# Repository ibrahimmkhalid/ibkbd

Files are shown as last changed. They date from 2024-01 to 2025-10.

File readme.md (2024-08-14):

# IBKBD
_Ibrahim's Keyboards_

- IBKBD Full
    - Custom physical layout, PCB, Case, and keymap
    - 4x6 + 5 + 3 _(Inspired heavily by [Dygma Defy](https://dygma.com/products/dygma-defy))_
    - Generic DSA keycaps
    - Kailh Midnight Pro Silent Tactile Switches
    - Pro Micro ATmega32U4 with type C port
    - check ./ibkbd-full/ for all relevant files

- IBKBD Mini
    - Custom physical layout, PCB, Case, and keymap
    - 3x5 + 3 (Inspired by Absolem and Corne keyboards)
    - DDC Choc keycaps
    - Sunset Tactile Choc Switches
    - NiceNano v2
    - check ./ibkbd-mini/ for all relevant files

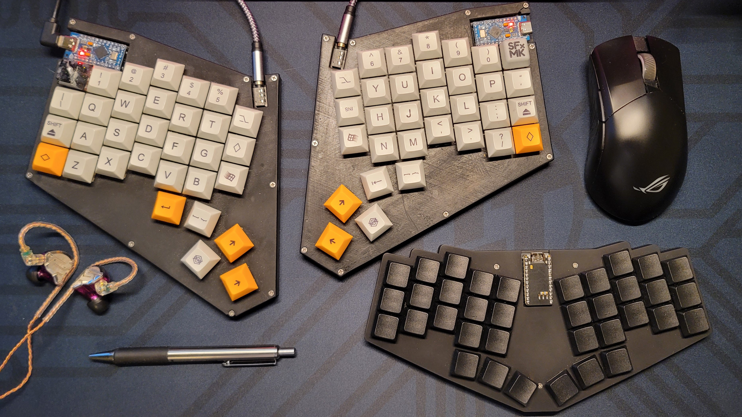
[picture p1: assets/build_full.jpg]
Final product

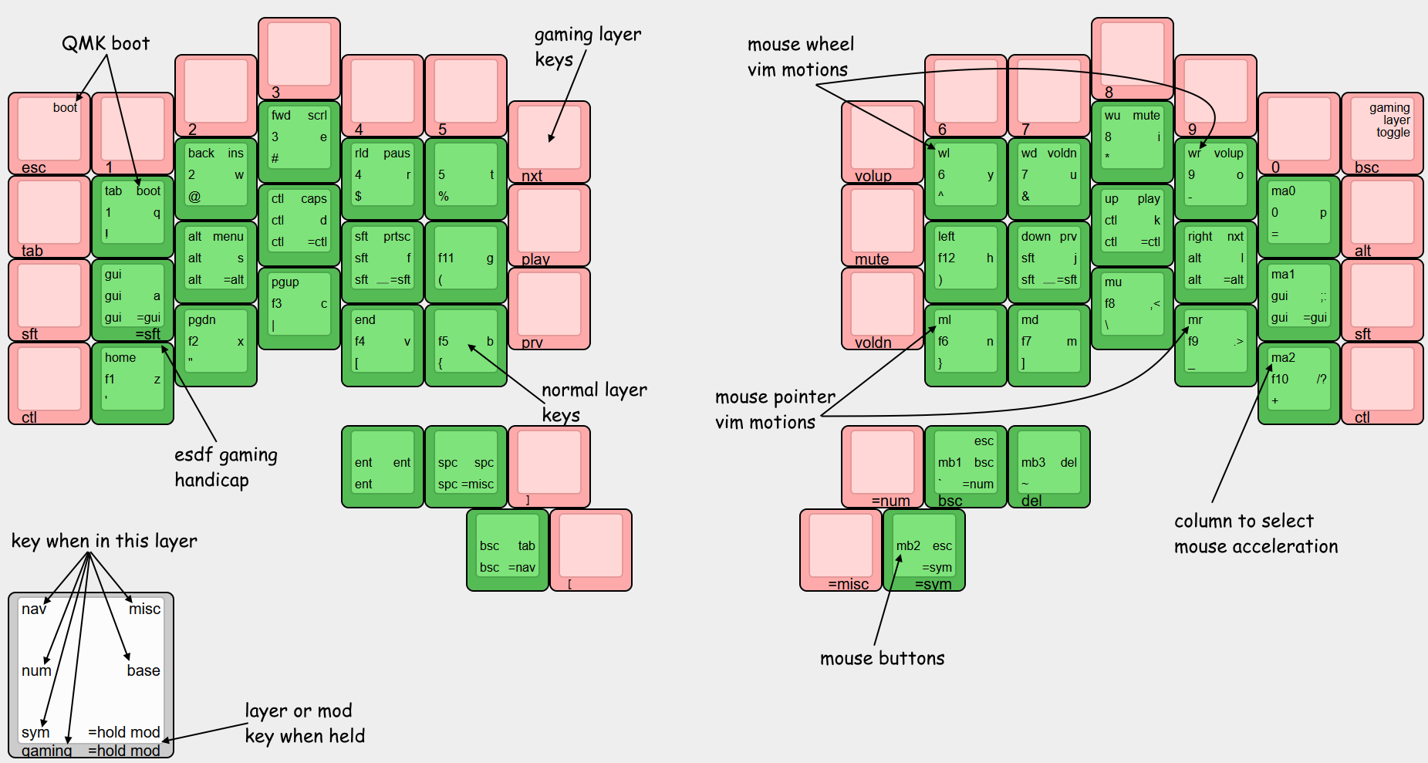
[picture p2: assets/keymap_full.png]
Keymap image


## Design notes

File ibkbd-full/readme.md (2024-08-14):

# IBKBD

_Ibrahim's Keyboard_

- Custom physical layout, PCB, Case, and keymap
- 4x6 + 5 + 3 _(Inspired heavily by [Dygma Defy](https://dygma.com/products/dygma-defy))_
- Generic DSA keycaps
- Kailh Midnight Pro Silent Tactile Switches
- Pro Micro ATmega32U4 with type C port

Originally, I was using all the keys in my base layer when i started my journey in ergonomic keyboards. Over time I was able to learn to use less keys and rely on better layer management. Though gaming is still best achieved when using the full board size. Current default layout is inspired by [Miryoku](https://github.com/manna-harbour/miryoku). My original keymap that used all keys on the board is saved in the "full" keymap.c file

#### In this project

- kicad pcb files
- 3D case files
- qmk configuration
- kle input

Keymap image

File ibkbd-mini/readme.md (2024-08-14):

# IBKBD

_Ibrahim's Keyboard_

- Custom physical layout, PCB, Case, and keymap
- 3x5 + 3 (Inspired by Absolem and Corne keyboards)
- DDC Choc keycaps
- Sunset Tactile Choc Switches
- NiceNano v2

I wanted to create an ultra portable version of the IBKBD-Full. This version uses low profile choc switches, does not have the gaming layer keys, and is a uni-body design.

#### In this project

- ergogen config
- completed kicad pcb
- generated 3d printing case files
- qmk keymap (substitute NiceNano)
- zmk keymap

Keymap image

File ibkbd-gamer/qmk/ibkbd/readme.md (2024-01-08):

# ibkbd

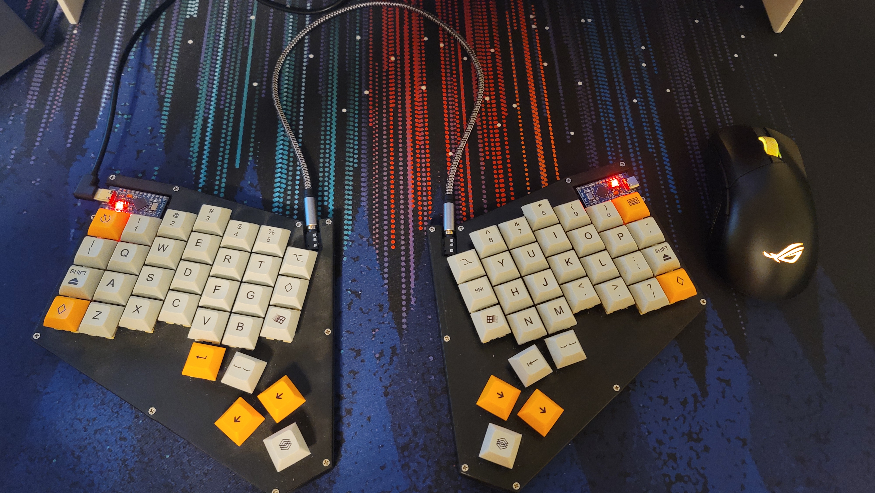
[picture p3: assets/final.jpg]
ibkbd


*A short description of the keyboard/project*

* Keyboard Maintainer: [Ibrahim Mansoor Khalid](https://github.com/ibrahimmkhalid)
* Hardware Supported: atmega32u4
* PCB and Case files: [ibrahimmkhalid/ibkbd](https://github.com/ibrahimmkhalid/ibkbd)

Make example for this keyboard (after setting up your build environment):

    make ibkbd:default

Flashing example for this keyboard:

    make ibkbd:default:flash

See the [build environment setup](https://docs.qmk.fm/#/getting_started_build_tools) and the [make instructions](https://docs.qmk.fm/#/getting_started_make_guide) for more information. Brand new to QMK? Start with our [Complete Newbs Guide](https://docs.qmk.fm/#/newbs).

## Bootloader

Enter the bootloader in 3 ways:

* **Bootmagic reset**: Hold down the key at (0,0) in the matrix (usually the top left key or Escape) and plug in the keyboard
* **Physical reset button**: Briefly press the button on the back of the PCB - some may have pads you must short instead
* **Keycode in layout**: Press the key mapped to `QK_BOOT` if it is available

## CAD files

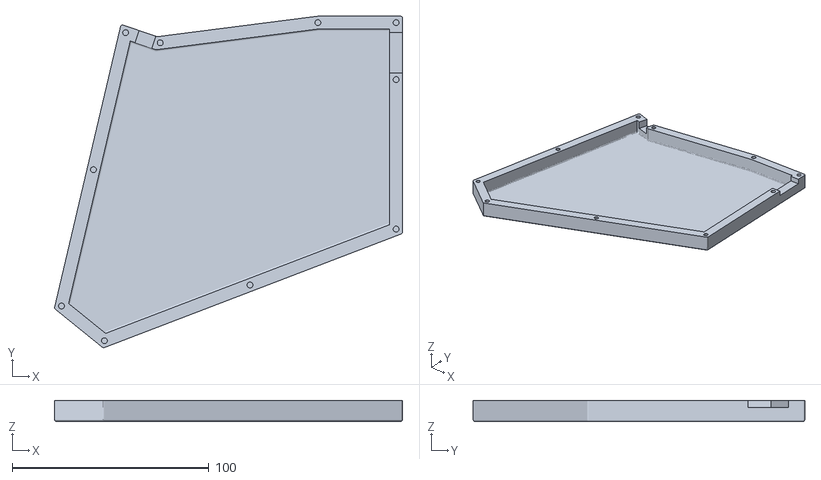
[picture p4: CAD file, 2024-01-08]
3d-files/base_right.stl
176.7 x 168.4 x 10.7

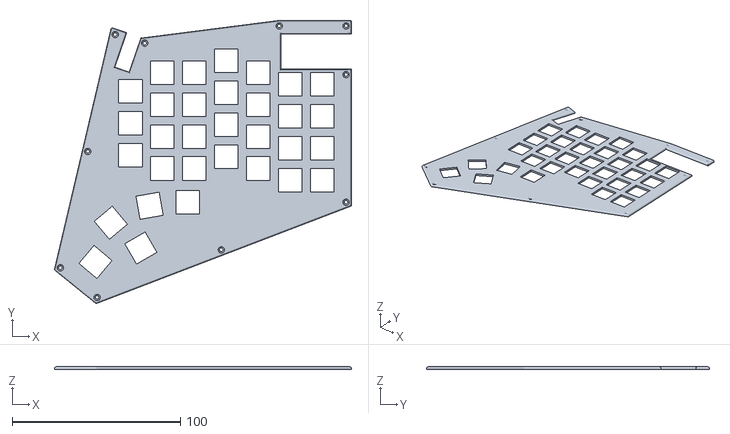
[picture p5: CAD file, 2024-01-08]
ibkbd-full/3d-files/plate_right.stl
176.7 x 168.4 x 1.50

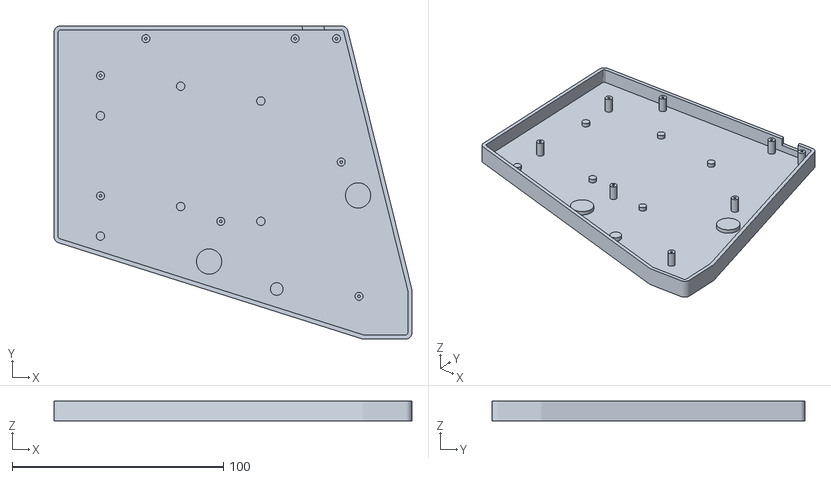
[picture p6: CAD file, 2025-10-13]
ibkbd-gamer/3d-files/bottom_plate.stl
169.6 x 148.3 x 9.40

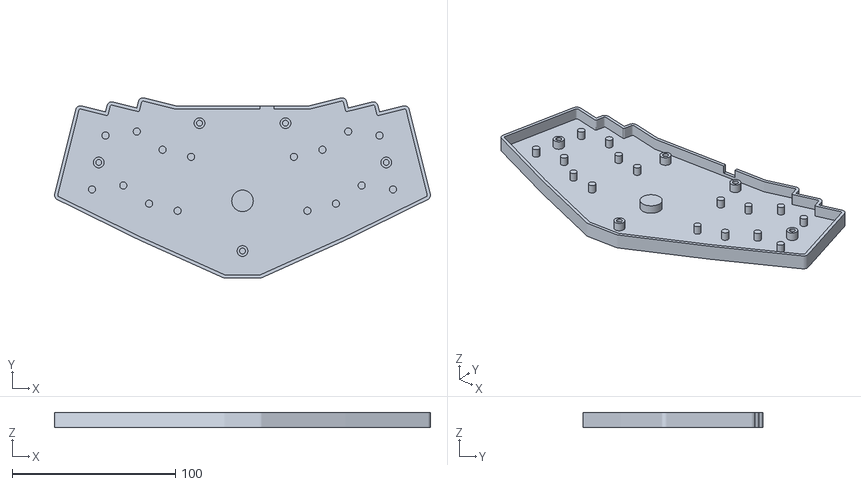
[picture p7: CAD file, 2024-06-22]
ibkbd-mini/3d-files/bottom_plate.stl
230.0 x 110.3 x 8.90

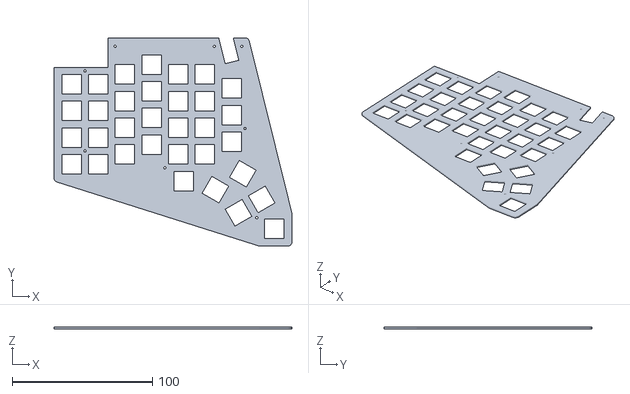
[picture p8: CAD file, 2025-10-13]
ibkbd-gamer/3d-files/top_plate.stl
169.6 x 148.3 x 1.20

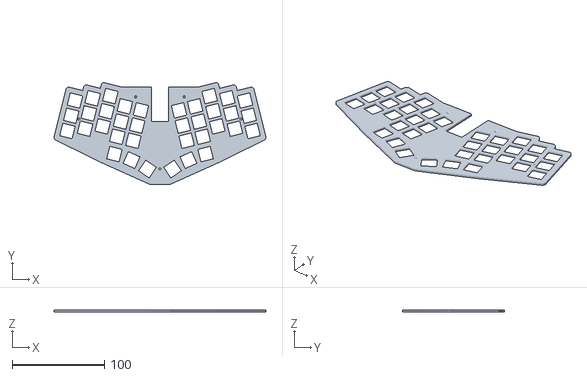
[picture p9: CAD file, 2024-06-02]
ibkbd-mini/3d-files/top_plate.stl
230.0 x 110.3 x 2.00

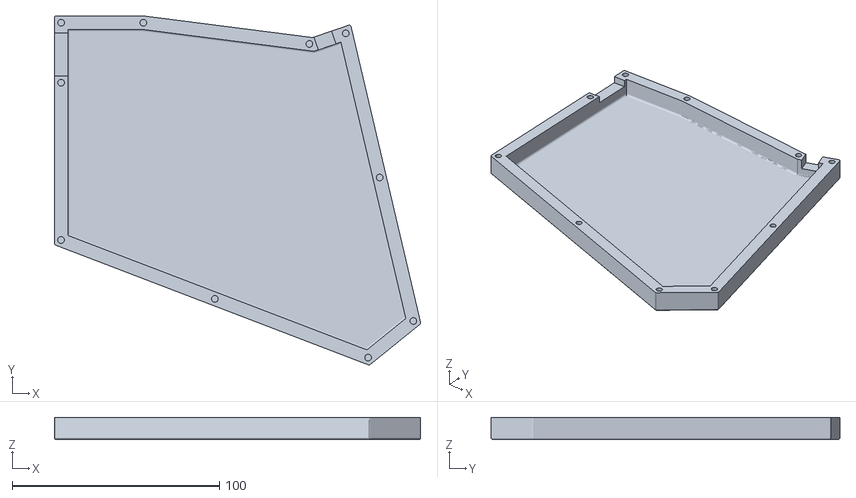
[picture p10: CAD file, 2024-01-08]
3d-files/base_left.stl
176.7 x 168.4 x 10.7

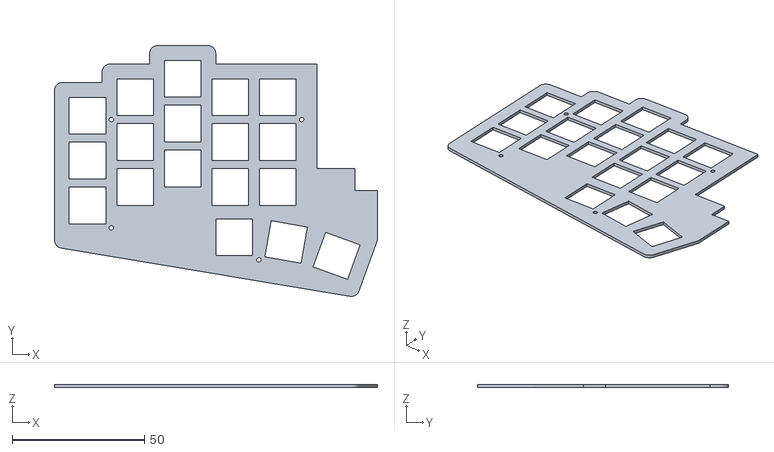
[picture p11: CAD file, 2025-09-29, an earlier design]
ibkbd-mini-split/3d-files/top_plate.stl
122.2 x 95.0 x 1.20

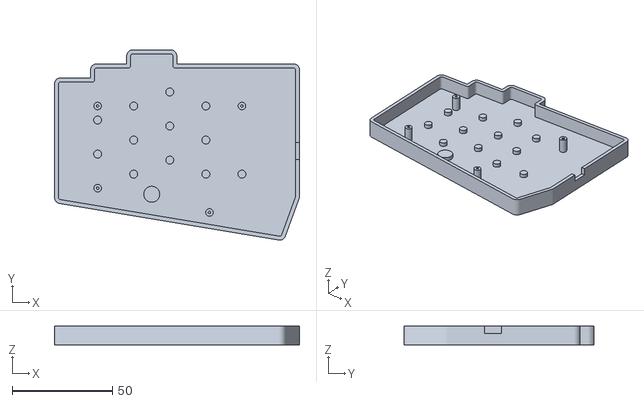
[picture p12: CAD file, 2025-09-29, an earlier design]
ibkbd-mini-split/3d-files/bottom_plate.stl
122.2 x 95.0 x 9.40

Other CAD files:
3d-files/plate_left.stl
ibkbd-full/3d-files/plate_left.stl

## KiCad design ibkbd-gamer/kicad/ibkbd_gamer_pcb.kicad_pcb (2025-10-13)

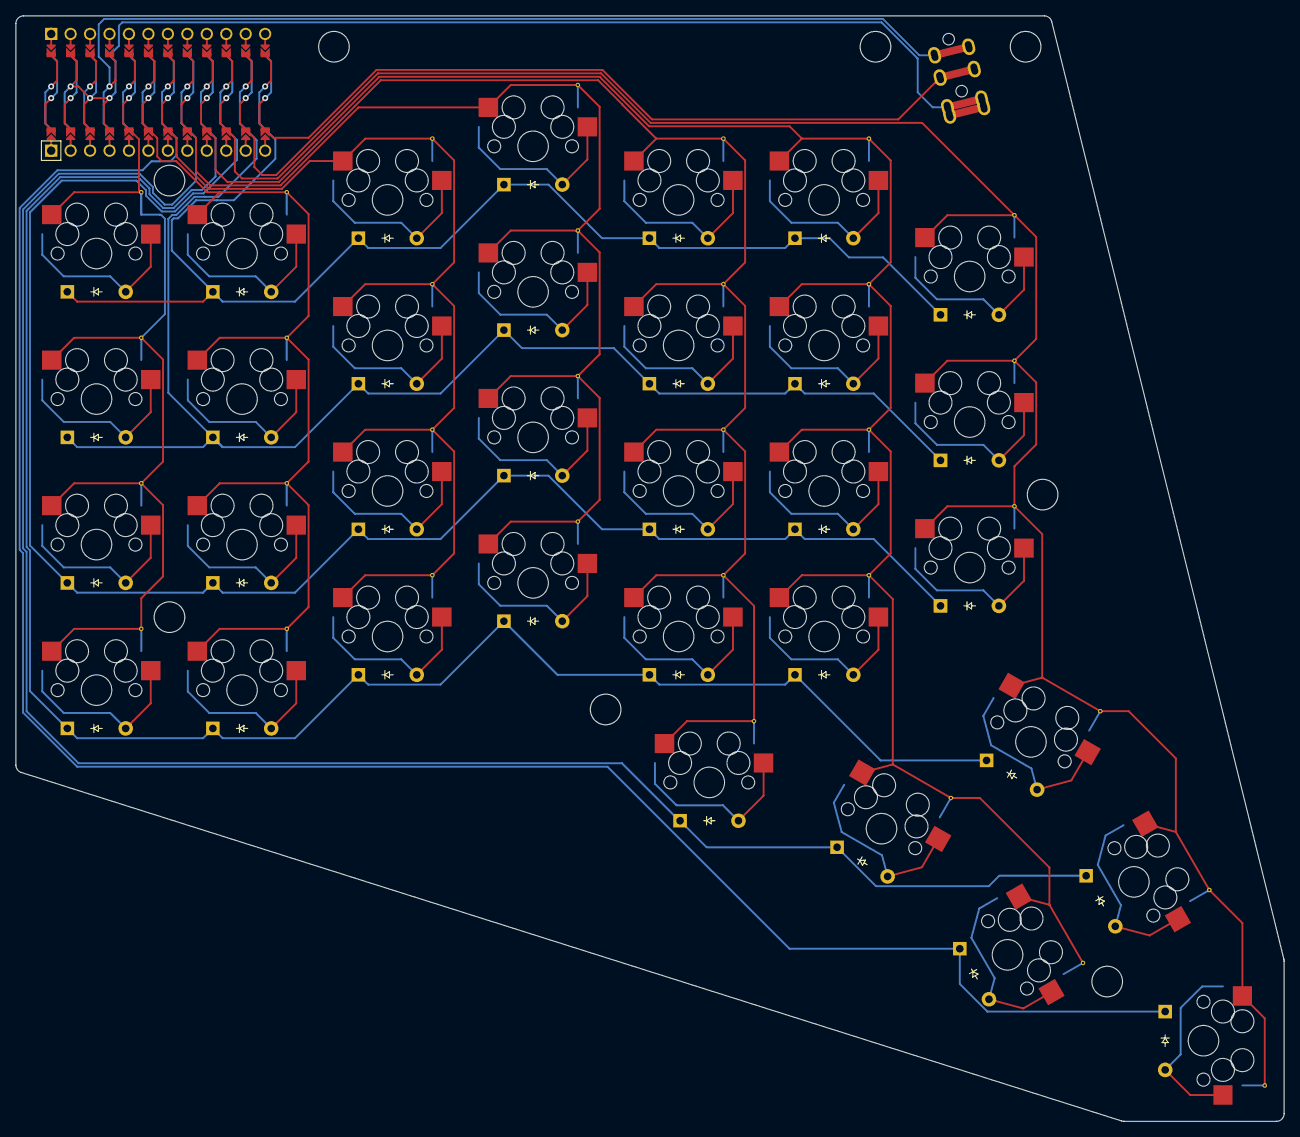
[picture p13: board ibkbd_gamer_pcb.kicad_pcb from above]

Board: 2 copper layers, 165.6 x 144.3 mm, 35 parts (0 on the bottom side), 16 nets.

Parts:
MCU1: ProMicro
S1, S2, S3, S4, S5, S6, S7, S8, S9, S10, S11, S12, S13, S14, S15, S16, S17, S18, S19, S20, S21, S22, S23, S24, S25, S26, S27, S28, S29, S30, S31, S32, S33: MXWD
TRRS1: TRRS-PJ-320A-dual

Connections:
GND: MCU1.2, MCU1.21, MCU1.22, TRRS1.1, TRRS1.2
P2: MCU1.20, S1.1, S2.1, S3.1, S4.1
P3: MCU1.19, S5.1, S6.1, S7.1, S8.1
P4: MCU1.18, S9.1, S10.1, S11.1, S12.1
P5: MCU1.17, S13.1, S14.1, S15.1, S16.1
P6: MCU1.16, S17.1, S18.1, S19.1, S20.1, S28.1
P7: MCU1.15, S21.1, S22.1, S23.1, S24.1, S29.1, S30.1
P8: MCU1.14, S25.1, S26.1, S27.1, S31.1, S32.1, S33.1
P9: MCU1.13, TRRS1.3
P10: MCU1.12, S4.2, S8.2, S12.2, S16.2, S20.2, S24.2, S27.2
P14: MCU1.10, S2.2, S6.2, S10.2, S14.2, S18.2, S22.2, S25.2
P15: MCU1.9, S1.2, S5.2, S9.2, S13.2, S17.2, S21.2, S32.2
P16: MCU1.11, S3.2, S7.2, S11.2, S15.2, S19.2, S23.2, S26.2
P18: MCU1.8, S28.2, S29.2, S31.2
P19: MCU1.7, S30.2, S33.2
VCC: MCU1.4, TRRS1.4

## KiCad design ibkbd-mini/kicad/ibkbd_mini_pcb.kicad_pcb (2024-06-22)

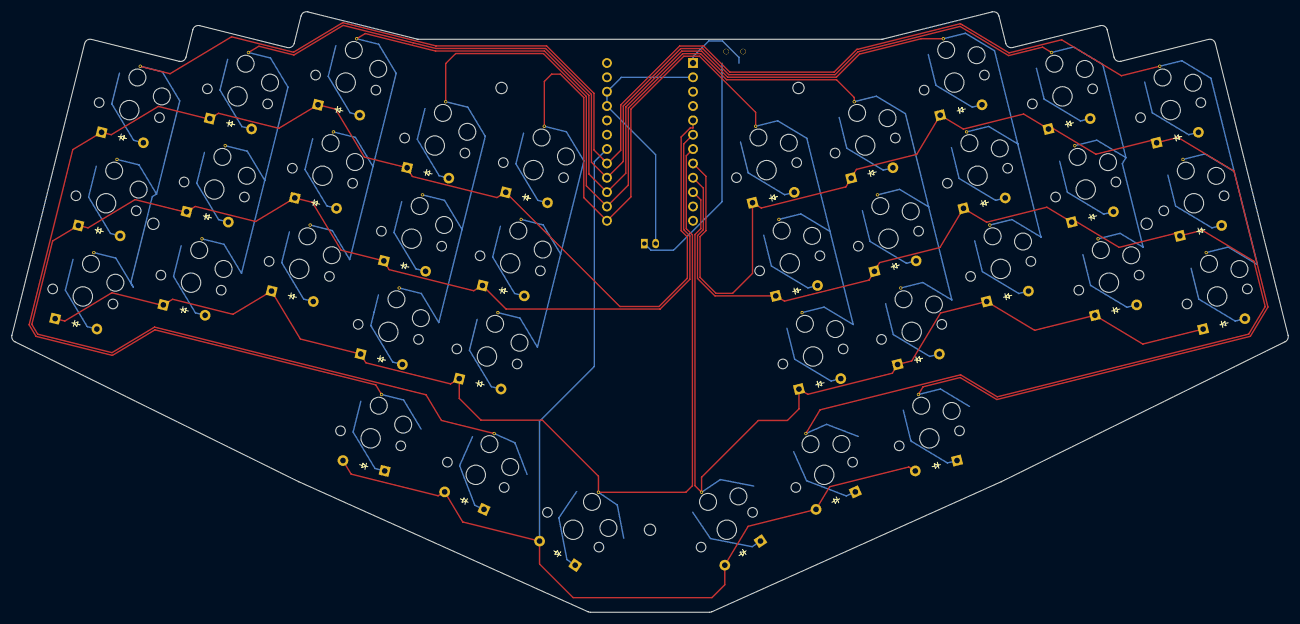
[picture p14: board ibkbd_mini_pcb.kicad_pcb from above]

Board: 2 copper layers, 226.0 x 106.3 mm, 75 parts (1 on the bottom side), 51 nets.

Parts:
D1, D2, D3, D4, D5, D6, D7, D8, D9, D10, D11, D12, D13, D14, D15, D16, D17, D18, D19, D20, D21, D22, D23, D24, D25, D26, D27, D28, D29, D30, D31, D32, D33, D34, D35, D36: ComboDiode
JST1: JST_PH_S2B-PH-K_02x2.00mm_Angled
MCU1: ProMicro
S1, S2, S3, S4, S5, S6, S7, S8, S9, S10, S11, S12, S13, S14, S15, S16, S17, S18, S19, S20, S21, S22, S23, S24, S25, S26, S27, S28, S29, S30, S31, S32, S33, S34, S35, S36: PG1350
T1: SPDT_C128955

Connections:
GND: JST1.2, MCU1.2, MCU1.15, MCU1.16
P4: D31.2, D32.2, D33.2, D34.2, D35.2, D36.2, MCU1.19
P5: MCU1.20, S1.2, S2.2, S3.2, S16.2, S17.2, S18.2
P6: MCU1.21, S4.2, S5.2, S6.2, S19.2, S20.2, S21.2
P7: MCU1.22, S7.2, S8.2, S9.2, S22.2, S23.2, S24.2
P8: MCU1.23, S10.2, S11.2, S12.2, S25.2, S26.2, S27.2
P9: MCU1.24, S13.2, S14.2, S15.2, S28.2, S29.2, S30.2
P14: D16.1, D19.1, D22.1, D25.1, D28.1, MCU1.10, S36.2
P15: D17.1, D20.1, D23.1, D26.1, D29.1, MCU1.9, S35.2
P18: D18.1, D21.1, D24.1, D27.1, D30.1, MCU1.8, S34.2
P19: D1.1, D4.1, D7.1, D10.1, D13.1, MCU1.7, S33.2
P20: D2.1, D5.1, D8.1, D11.1, D14.1, MCU1.6, S32.2
P21: D3.1, D6.1, D9.1, D12.1, D15.1, MCU1.5, S31.2
RAW: MCU1.1, T1.2
batswitch: JST1.1, T1.1
index_bottom: D10.2, S10.1
index_home: D11.2, S11.1
index_top: D12.2, S12.1
inner_bottom: D13.2, S13.1
inner_home: D14.2, S14.1
inner_key: D31.1, S31.1
inner_top: D15.2, S15.1
mid_key: D32.1, S32.1
middle_bottom: D7.2, S7.1
middle_home: D8.2, S8.1
middle_top: D9.2, S9.1
mirror_index_bottom: D25.2, S25.1
mirror_index_home: D26.2, S26.1
mirror_index_top: D27.2, S27.1
mirror_inner_bottom: D28.2, S28.1
mirror_inner_home: D29.2, S29.1
mirror_inner_key: D34.1, S34.1
mirror_inner_top: D30.2, S30.1
mirror_mid_key: D35.1, S35.1
mirror_middle_bottom: D22.2, S22.1
mirror_middle_home: D23.2, S23.1
mirror_middle_top: D24.2, S24.1
mirror_outer_key: D36.1, S36.1
mirror_pinky_bottom: D16.2, S16.1
mirror_pinky_home: D17.2, S17.1
mirror_pinky_top: D18.2, S18.1
mirror_ring_bottom: D19.2, S19.1
mirror_ring_home: D20.2, S20.1
mirror_ring_top: D21.2, S21.1
outer_key: D33.1, S33.1
pinky_bottom: D1.2, S1.1
pinky_home: D2.2, S2.1
pinky_top: D3.2, S3.1
ring_bottom: D4.2, S4.1
ring_home: D5.2, S5.1
ring_top: D6.2, S6.1

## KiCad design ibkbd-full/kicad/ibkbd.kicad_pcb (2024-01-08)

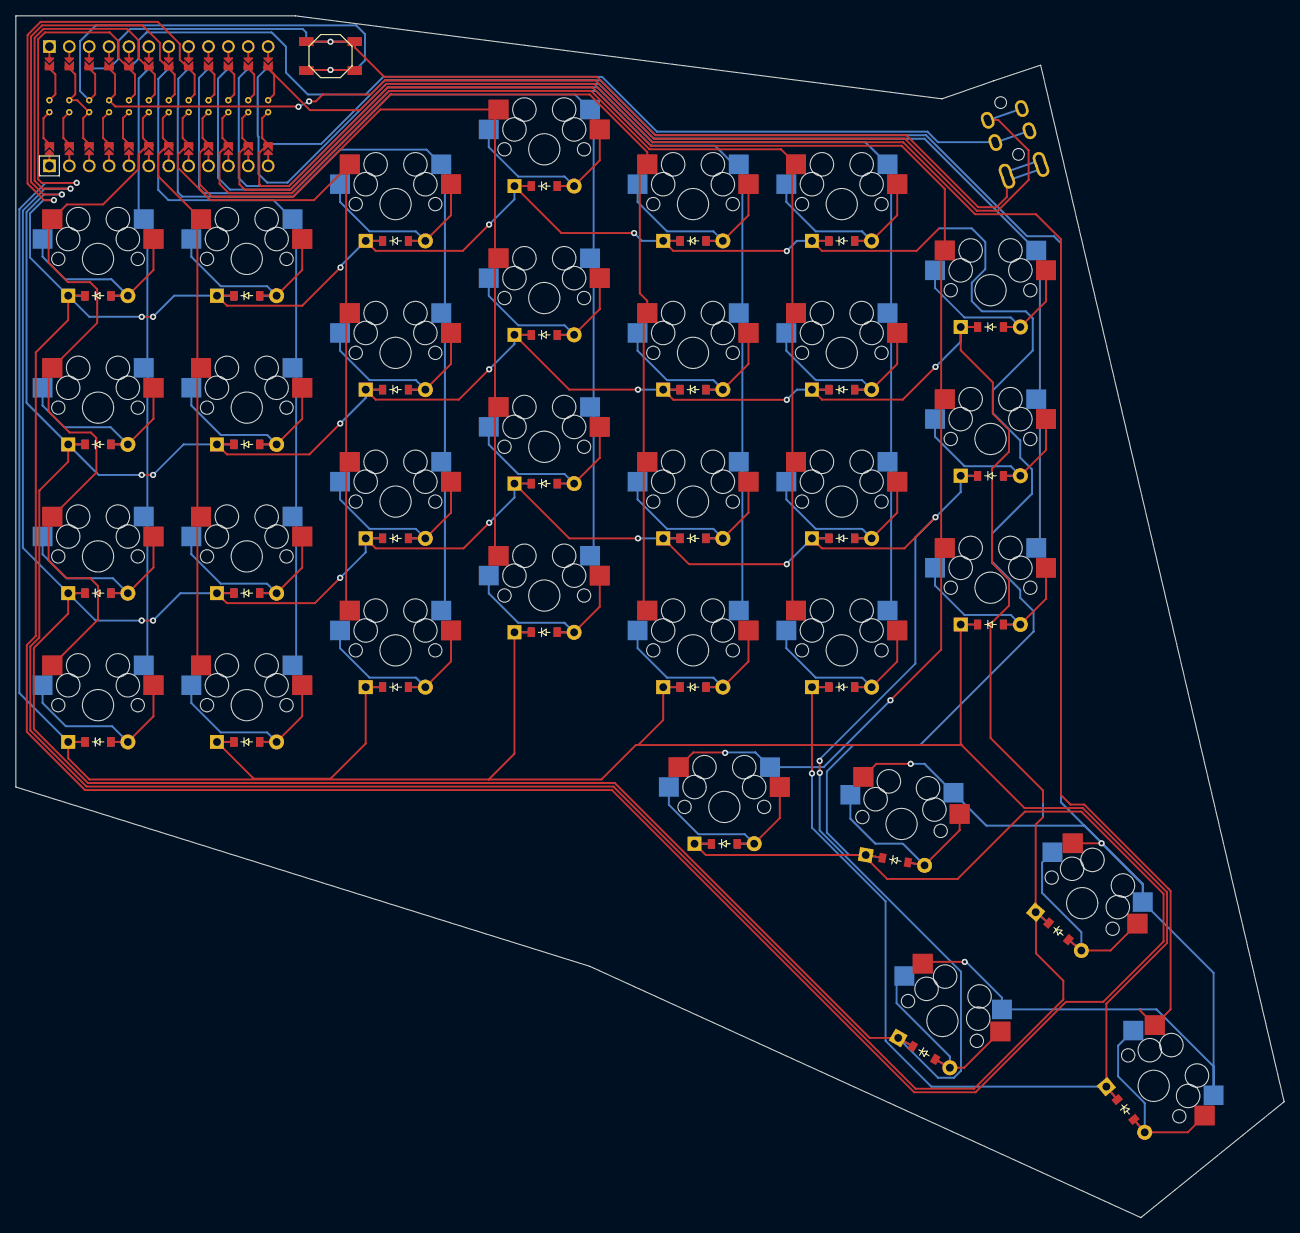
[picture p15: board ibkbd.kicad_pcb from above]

Board: 2 copper layers, 162.0 x 153.5 mm, 67 parts (0 on the bottom side), 46 nets.

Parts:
B1, B2: SW_TACT_ALPS_SKQGABE010
D1, D2, D3, D4, D5, D6, D7, D8, D9, D10, D11, D12, D13, D14, D15, D16, D17, D18, D19, D20, D21, D22, D23, D24, D25, D26, D27, D28, D29, D30, D31, D32: ComboDiode
MCU1: ProMicro
S1, S2, S3, S4, S5, S6, S7, S8, S9, S10, S11, S12, S13, S14, S15, S16, S17, S18, S19, S20, S21, S22, S23, S24, S25, S26, S27, S28, S29, S30, S31, S32: MX

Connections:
GND: B1.2, B2.2, MCU1.2, MCU1.21, MCU1.22
P3: MCU1.19, S1.2, S2.2, S3.2, S4.2
P4: MCU1.18, S5.2, S6.2, S7.2, S8.2
P5: MCU1.17, S9.2, S10.2, S11.2, S12.2
P6: MCU1.16, S13.2, S14.2, S15.2, S16.2
P7: MCU1.15, S17.2, S18.2, S19.2, S20.2
P8: MCU1.14, S21.2, S22.2, S23.2, S24.2
P9: MCU1.13, S25.2, S26.2, S27.2, S28.2
P10: MCU1.12, S29.2, S30.2, S31.2, S32.2
P18: D4.1, D4.2, D8.1, D8.2, D12.1, D12.2, D16.1, D16.2, D20.1, D20.2, D24.1, D24.2, D28.1, D28.2, D29.1, D29.2, MCU1.8
P19: D3.1, D3.2, D7.1, D7.2, D11.1, D11.2, D15.1, D15.2, D19.1, D19.2, D23.1, D23.2, D27.1, D27.2, D30.1, D30.2, MCU1.7
P20: D2.1, D2.2, D6.1, D6.2, D10.1, D10.2, D14.1, D14.2, D18.1, D18.2, D22.1, D22.2, D26.1, D26.2, D31.1, D31.2, MCU1.6
P21: D1.1, D1.2, D5.1, D5.2, D9.1, D9.2, D13.1, D13.2, D17.1, D17.2, D21.1, D21.2, D25.1, D25.2, D32.1, D32.2, MCU1.5
RST: B1.1, B2.1, MCU1.3
extra_bottom: D25.1, D25.2, S25.1
extra_home: D26.1, D26.2, S26.1
extra_top: D27.1, D27.2, S27.1
far_ext: D31.1, D31.2, S31.1
far_ext2: D32.1, D32.2, S32.1
far_thumb: D30.1, D30.2, S30.1
home_thumb: D29.1, D29.2, S29.1
index_bottom: D17.1, D17.2, S17.1
index_home: D18.1, D18.2, S18.1
index_num: D20.1, D20.2, S20.1
index_top: D19.1, D19.2, S19.1
inner_bottom: D21.1, D21.2, S21.1
inner_home: D22.1, D22.2, S22.1
inner_num: D24.1, D24.2, S24.1
inner_top: D23.1, D23.2, S23.1
middle_bottom: D13.1, D13.2, S13.1
middle_home: D14.1, D14.2, S14.1
middle_num: D16.1, D16.2, S16.1
middle_top: D15.1, D15.2, S15.1
near_thumb: D28.1, D28.2, S28.1
outer_bottom: D1.1, D1.2, S1.1
outer_home: D2.1, D2.2, S2.1
outer_num: D4.1, D4.2, S4.1
outer_top: D3.1, D3.2, S3.1
pinky_bottom: D5.1, D5.2, S5.1
pinky_home: D6.1, D6.2, S6.1
pinky_num: D8.1, D8.2, S8.1
pinky_top: D7.1, D7.2, S7.1
ring_bottom: D9.1, D9.2, S9.1
ring_home: D10.1, D10.2, S10.1
ring_num: D12.1, D12.2, S12.1
ring_top: D11.1, D11.2, S11.1

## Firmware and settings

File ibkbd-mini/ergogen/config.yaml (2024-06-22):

units:
  p: 2
  angle: -14
  thumb_splay_angle: -10
  mirror_dist: 1.25U
  pU: U + p
  $default_spread: cx
  $default_padding: cy
  m2_hole_radius_pcb: 1.1
  m2_hole_insert_radius_expand: 0.7
  m2_hole_standoff_radius_expand: 1.5
  m2_height: 8 - 1.6 - 1.2 # total screw height - screw head height - adjustment
  pcb_thickness: 1.6
  parts_clearance: 2.5 + 0.8
  plate_thickness: 2
  plate_switch_hole: 13.9
  wall_height: (m2_height - pcb_thickness) + parts_clearance
  wall_thickness: 2
  switch_gap: 0.2
  switch_clip_height: 0.8
  promicro_pos_x: 0
  promicro_pos_y: 5
  promicro_angle: -90
  slider_pos_x: 15
  slider_pos_y: 21
points:
  zones:
    main:
      anchor.shift: [100, -100]
      rotate: angle
      mirror: &mirror
        ref: main_inner_bottom
        shift: mirror_dist
      columns:
        pinky:
          key:
            column_net: P5
        ring:
          key:
            column_net: P6
            stagger: 7
        middle:
          key:
            column_net: P7
            stagger: 7
        index:
          key:
            column_net: P8
            stagger: -7
        inner:
          key:
            column_net: P9
      rows:
        bottom:
          row_net: P19
          mirror.row_net: P14
        home:
          row_net: P20
          mirror.row_net: P15
        top:
          row_net: P21
          mirror.row_net: P18
    thumb:
      mirror: &mirror
        ref: main_inner_bottom
        shift: mirror_dist
      anchor:
        ref: main_inner_bottom
        shift: [-0.55U, -U]
      columns:
        inner:
          key:
            shift: [-6, 0]
            column_net: P21
            mirror.column_net: P18
        mid:
          key:
            splay: thumb_splay_angle
            shift: [-4, -2.5]
            column_net: P20
            mirror.column_net: P15
        outer:
          key:
            splay: thumb_splay_angle
            shift: [-1.5, -4.7]
            column_net: P19
            mirror.column_net: P14
      rows:
        key:
          row_net: P4
          mirror.row_net: P4
outlines:
  _padded_keys:
    - what: rectangle
      where: true
      size: pU
  _keys_clip:
    - what: rectangle
      where: true
      size: plate_switch_hole + 0.8
  _glue_block:
    - what: polygon
      points:
        - ref: main_middle_top
          shift: [0.5pU, 0.5pU]
        - ref: main_pinky_bottom
          shift: [-0.5pU, -0.5pU]
        - ref: thumb_inner_key
          shift: [-0.5pU, -0.5pU]
        - ref: thumb_outer_key
          shift: [0.5pU, -0.5pU]
        - ref: mirror_thumb_outer_key
          shift: [0.5pU, -0.5pU]
        - ref: mirror_thumb_inner_key
          shift: [-0.5pU, -0.5pU]
        - ref: mirror_main_pinky_bottom
          shift: [-0.5pU, -0.5pU]
        - ref: mirror_main_middle_top
          shift: [0.5pU, 0.5pU]
  _promicro_slot:
    - what: rectangle
      size: [34, 18.5]
      where:
        - aggregate.parts:
            - main_inner_top
            - mirror_main_inner_top
          shift: [promicro_pos_x, promicro_pos_y]
          rotate: promicro_angle
  _slider_slot:
    - what: rectangle
      size: [8.5, 8.5]
      where:
        - aggregate.parts:
            - main_inner_top
            - mirror_main_inner_top
          shift: [slider_pos_x, slider_pos_y]
          rotate: promicro_angle
  _base_outline:
    - what: outline
      name: _padded_keys
    - what: outline
      name: _glue_block
  _pcb_drill:
    - what: circle
      radius: m2_hole_radius_pcb
      where:
        - aggregate.parts:
            - thumb_outer_key
            - mirror_thumb_outer_key
    - what: circle
      radius: m2_hole_radius_pcb
      where: /^.*ring_home.*/
      adjust:
        shift: [-0.5*cx, -0.5*cy]
    - what: circle
      radius: m2_hole_radius_pcb
      where: /^.*inner_top.*/
      adjust:
        shift: [-0.5*cx, 0.75*cy]
  _case_standoff_heat_inserts:
    - what: outline
      name: _pcb_drill
      expand: m2_hole_insert_radius_expand
  _case_standoff:
    - what: outline
      name: _case_standoff_heat_inserts
      expand: m2_hole_standoff_radius_expand
    - what: circle
      radius: 6*m2_hole_radius_pcb
      where:
        - aggregate.parts:
            - main_inner_bottom
            - mirror_main_inner_bottom
    - what: circle
      radius: 2*m2_hole_radius_pcb
      where: /^.*(ring|middle|index|inner)_(top|bottom).*/
      adjust:
        shift: [-0.5*cx, -0.5*cy]
  _main_outline:
    - what: outline
      name: _base_outline
      fillet: 1
  _case_outline:
    - what: outline
      name: _main_outline
      expand: wall_thickness
  _wall_outline:
    - what: outline
      name: _case_outline
    - what: outline
      name: _main_outline
      operation: subtract
  _wall_cutout_for_slider:
    - what: outline
      name: _wall_outline
    - what: outline
      name: _slider_slot
      operation: subtract
      adjust.shift: [0, 5]
  top_plate_outline:
    - what: outline
      name: _case_outline
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

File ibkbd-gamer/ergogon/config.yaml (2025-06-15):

units:
  p: 2
  pU: U + p
  m2_screw_radius: 1.6 / 2 # diameter based on mcmaster 99461A913
  m2_hole_radius_pcb: m2_screw_radius * 2.5 # enough plastic around screw to hold strongly
  m2_hole_radius_plate_expand: m2_hole_radius_pcb - (m2_screw_radius + 0.05) # pcb radius - actual desired hole size (enough wiggle room for plate for easy screw inserting and removal)
  m2_hole_radius_insert_expand: m2_hole_radius_pcb - 0.8 * m2_screw_radius # pcb radius - actual desired hole size (80% of screw width, so there is enough material to grab on to)
  pcb_thickness: 1.6
  plate_thickness: 1.2
  plate_switch_hole: 13.9
  wall_thickness: 2
  switch_gap: 5 - plate_thickness # distance from the top of the pcb to the bottom of the plate
  wall_height: 8 - plate_thickness + 0.6 # screw height - plate_thickness + adjustment to allow 2mm space under pcb
  promicro_pos_x: U - 11
  promicro_pos_y: U + 2
  promicro_l: 36
  promicro_w: 18.5
  trrs_l: 15
  trrs_w: 6
  trrs_pos_x: -2
  trrs_pos_y: U + 9
  trrs_angle: 360 - 76
  trrs_angle_rad: trrs_angle * (pi / 180)
  trrs_forward: 10
  trrs_gap: 2
points:
  zones:
    matrix:
      anchor:
        shift: [100, -150] # Fix KiCad placement
      columns:
        outer:
          key:
            column_net: P2
        pinky:
          key:
            column_net: P3
        ring:
          key:
            stagger: 7
            column_net: P4
        middle:
          key:
            stagger: 7
            column_net: P5
        index:
          key:
            stagger: -7
            column_net: P6
        inner:
          key:
            column_net: P7
        extra:
          key:
            stagger: 9
            column_net: P8
          rows.bottom: $unset
      rows:
        bottom:
          row_net: P15
        home:
          row_net: P14
        top:
          row_net: P16
        num:
          row_net: P10
    thumbfan:
      anchor:
        ref: matrix_index_bottom
        shift: [4, -U]
      columns:
        near:
          key:
            column_net: P6
            row_net: P18
        home:
          key:
            column_net: P7
            row_net: P18
            origin: [-U/2, -U/2]
            splay: -30
        far:
          key:
            column_net: P7
            row_net: P19
            origin: [-U/2, -U/2]
            splay: -30
        gk1:
          key:
            column_net: P8
            row_net: P18
            spread: 0
            stagger: U
        gk2:
          key:
            column_net: P8
            row_net: P15
            spread: -U-3.5
            stagger: 0-2.5
            rotate: 30
        gk3:
          key:
            column_net: P8
            row_net: P19
            shift: [U+7, 0]
            rotate: -30
      rows:
        thumb:
outlines:
  _true_keys_debug:
    - what: rectangle
      where: true
      size: [18, 18]
  _padded_keys:
    - what: rectangle
      where: true
      size: pU
  _glue_block:
    - what: polygon
      points:
        - ref: matrix_outer_num
          shift: [-0.5pU, 0.5pU + promicro_w + p]
        - ref: matrix_outer_bottom
          shift: [-0.5pU, -0.5pU]
        - ref: thumbfan_gk3_thumb
          shift: [0.5pU, -0.5pU]
        - ref: thumbfan_gk3_thumb
          shift: [0.5pU, 0.5pU]
        - ref: thumbfan_gk3_thumb
          shift: [-0.5pU, 0.5pU]
        - ref: matrix_extra_num
          shift: [0.5pU, 0.5pU + promicro_w + 3 + p]
  _promicro_slot:
    - what: rectangle
      size: [promicro_l + 5, promicro_w + 5]
      where:
        ref: matrix_outer_num
        shift: [promicro_pos_x - 2.5, promicro_pos_y + 2.5]
  _trrs_slot_orig:
    - what: rectangle
      size: [trrs_l, trrs_w]
      where:
        ref: matrix_extra_num
        shift: [trrs_pos_x, trrs_pos_y]
        rotate: trrs_angle
  _trrs_slot:
    - what: rectangle
      size: [trrs_l + trrs_forward + trrs_gap, trrs_w + 2 * trrs_gap]
      where:
        ref: matrix_extra_num
        shift:
          [
            trrs_pos_x - (trrs_forward - trrs_gap)/2 * cos(trrs_angle_rad),
            trrs_pos_y - (trrs_forward - trrs_gap)/2 * sin(trrs_angle_rad),
          ]
        rotate: trrs_angle
  _base_outline: [_padded_keys, _glue_block]
  _pcb_drill:
    - what: circle
      radius: m2_hole_radius_pcb
      where:
        - matrix_outer_num
        - matrix_outer_bottom
        - matrix_extra_home
        - thumbfan_far_thumb
      adjust:
        shift: [0.5*U, 0.5*U]
    - what: circle
      radius: m2_hole_radius_pcb
      where:
        - matrix_index_bottom
      adjust:
        shift: [-0.5*U, -0.5*U]
    - what: circle
      radius: m2_hole_radius_pcb
      where:
        - matrix_ring_num
      adjust:
        shift: [-7, 20]
    - what: circle
      radius: m2_hole_radius_pcb
      where:
        - matrix_inner_num
      adjust:
        shift: [6.7, 20]
    - what: circle
      radius: m2_hole_radius_pcb
      where:
        - matrix_extra_num
      adjust:
        shift: [7.3, 30]
  _top_plate_drill:
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

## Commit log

2024-01-10 refactor: move all file to its own subproject allow possible space for more projects
    [base_left.stl, base_right.stl, ibkbd.kicad_pcb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]
2024-01-10 Revert "refactor: move all file to its own subproject"
    This reverts commit 40ac549ca16cb1e7f994a59c04abda420fa7acbc.
    [base_left.stl, base_right.stl, ibkbd.kicad_pcb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]
2024-01-10 Revert "Revert "refactor: move all file to its own subproject""
    This reverts commit 9ab7bfc7b2d63e8a07769d03e0b0267bc4c02f83.
    [base_left.stl, base_right.stl, ibkbd.kicad_pcb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]
2024-01-11 add pcb outline
2024-01-11 add pcb and fix nets
2024-01-11 add mounting holes
2024-01-11 use official ergogen and local footprints
2024-01-12 add battery and slider switch
2024-01-12 using github action to generate pcb and gerber
2024-01-12 update pcb name
2024-01-12 dont block screw with mcu
2024-01-13 add case and other minor fixes
    [config.yaml]
2024-01-13 update make script to convert jscad to stl
2024-01-15 overhaul case design
2024-01-16 routed pcb
    [ibkbd_mini_pcb.kicad_pcb]
2024-01-16 rename folder
    [ibkbd_mini_pcb.kicad_pcb]
2024-01-17 reverse diode direction
    [ibkbd_mini_pcb.kicad_pcb]
2024-01-19 add fix for kicad placement
    [config.yaml]
2024-01-19 fix diode direction on thumb keys, update routed pcb
    [ibkbd_mini_pcb.kicad_pcb]
2024-02-02 update pcb to use hotswap choc switches
    [ibkbd_mini_pcb.kicad_pcb]
2024-02-03 udpate tracks and position of slider
    [ibkbd_mini_pcb.kicad_pcb]
2024-02-04 update kicad pcb
    [ibkbd_mini_pcb.kicad_pcb]
2024-02-04 update mount hole position to accomodate hotswap sockets
    [ibkbd_mini_pcb.kicad_pcb]
2024-06-02 mini:update 3D specifications
    [bottom_plate.stl, top_plate.stl]
2024-06-05 mini: udpate bottom plate
    [bottom_plate.stl]
2024-06-13 mini: clean up pcb
    [ibkbd_mini_pcb.kicad_pcb]
2024-06-22 mini: flip mcu to correct side up
    [ibkbd_mini_pcb.kicad_pcb]
2024-06-22 fix standoff holes
    [bottom_plate.stl]
2024-08-14 remove old files
    [ibkbd_mini_pcb.kicad_pcb]
2025-05-19 add pcb, still needs refinement
2025-05-21 tentative complete case
2025-05-21 fix standoff positions
2025-05-21 make reversable pcb
2025-05-21 i dont remember why i did this so im just gonna remove it 🤷
2025-05-21 added extra screw
2025-05-21 fix KiCad placement
2025-05-22 create unified footprint
2025-05-22 fix traces in footprint
    [config.yaml]
2025-05-22 unrouted final pcb
    [ibkbd_gamer_pcb.kicad_pcb]
2025-05-22 case files
    tentative
    top plate needs to be mirrored when printing
    [bottom_plate.stl, top_plate.stl]
2025-05-30 update pcb
    [ibkbd_gamer_pcb.kicad_pcb]
2025-06-01 make reverse standoffs
2025-06-01 Revert "make reverse standoffs"
    This reverts commit e2e1922b3e0b0666c3336e85e830020ad5ffaf08.
    [config.yaml]
2025-06-04 move to through hole design
    [bottom_plate.stl, ibkbd_gamer_pcb.kicad_pcb, top_plate.stl]
2025-06-16 did stuff
    keys, outline, pcb, footprints
